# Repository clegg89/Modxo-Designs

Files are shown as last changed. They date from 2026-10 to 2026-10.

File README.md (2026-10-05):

# Modxo Designs
A set of custom [Modxo](https://github.com/Team-Resurgent/modxo) boards.

All boards have 128Mb (16MB) of flash and use a custom board variant.

## Comparison

| Feature | Micro | Mini | Mega |
| --- | ----- | ---- | ---- |
| 128Mb (16MB) of flash | ✅ | ✅ | ✅ |
| On-board RGB LED | ✅ | ✅ | ✅ |
| USB port for DFU Update | ✅ | ✅ | ✅ |
| D0 Port/Solder Pad | ✅ | ✅ | ✅ |
| Xbox I2C Port | ❌ | ✅ | ✅ |
| LCD Support | ❌ | ✅ | ✅ |
| RGB Output Port | ❌ | ✅ | ✅ |
| Expansion I2C Port | ❌ | ✅ | ✅ |
| RP2350 MCU | ❌ | ❌ | ✅ |
| UART Port | ❌ | ❌ | ✅ |
| Micro SD Card Slot | ❌ | ❌ | ✅ |
| Debug Support | ❌ | ❌ | ✅ |
| R3MUX (X3) Support | ❌ | ❌ | ✅ |

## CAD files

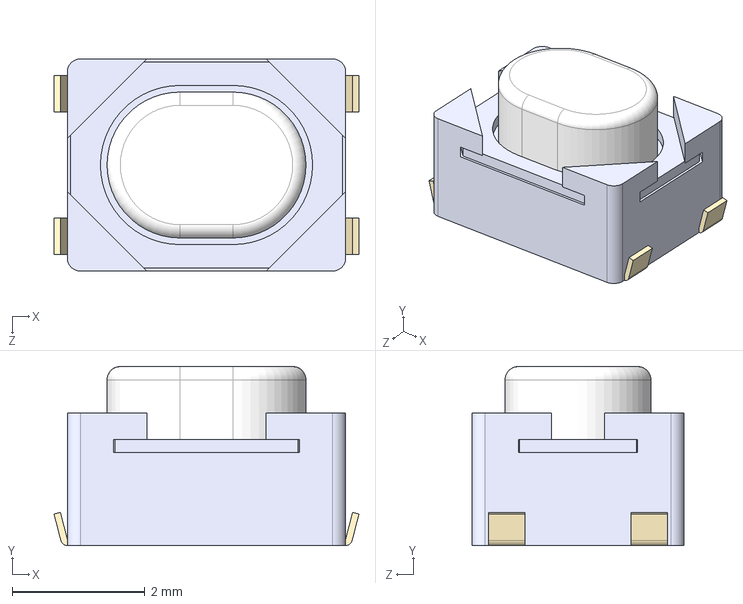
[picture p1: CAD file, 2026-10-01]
Models/PTS810SJK250SMTR LFS.STEP
4.60 x 2.70 x 3.20 mm

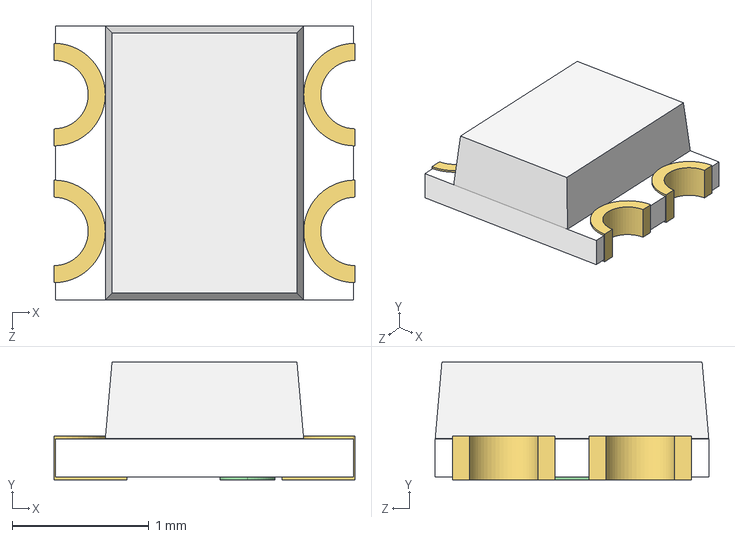
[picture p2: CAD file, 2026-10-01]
Models/WS2812-2020.STEP
2.20 x 0.86 x 2.00 mm

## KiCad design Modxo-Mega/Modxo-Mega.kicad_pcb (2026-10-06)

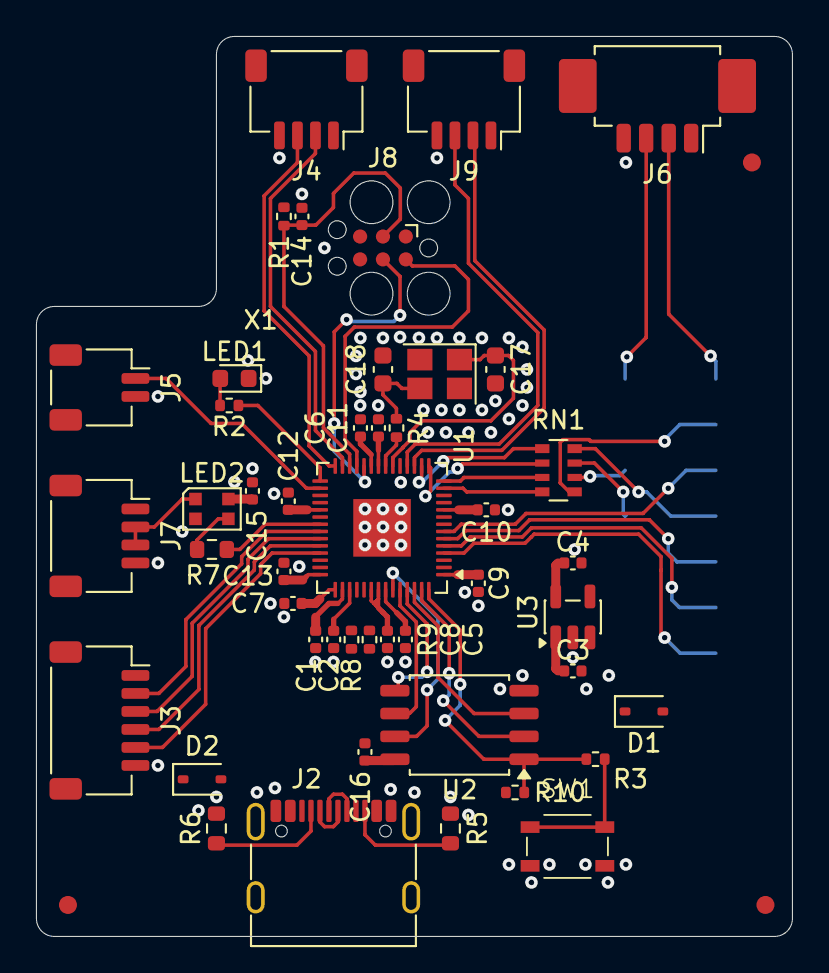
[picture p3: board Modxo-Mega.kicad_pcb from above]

Board: 2 copper layers, 42.0 x 50.0 mm, 50 parts (1 on the bottom side), 53 nets.

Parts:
C1, C2, C3, C4: 1u; C_0402_1005Metric
C5, C6, C7, C8, C9, C10, C11, C12, C13, C14, C15, C16: 100n; C_0402_1005Metric
C17, C18: 15p; C_0603_1608Metric
D1, D2: 1N5819WS; D_SOD-323
FID1, FID2, FID3: Fiducial; Fiducial_1mm_Mask2mm
J1: LPC; PinSocket_2x08_P2.54mm_Vertical_SMD
J2: USB-C; USB_C_Receptacle_G-Switch_GT-USB-7010ASV
J3: LCD; JST_SH_SM06B-SRSS-TB_1x06-1MP_P1.00mm_Horizontal
J4: UART; JST_SH_SM04B-SRSS-TB_1x04-1MP_P1.00mm_Horizontal
J5: D0; JST_SH_SM02B-SRSS-TB_1x02-1MP_P1.00mm_Horizontal
J6: OXHD; Molex_PicoBlade_53261-0471_1x04-1MP_P1.25mm_Horizontal
J7: RGB; JST_SH_SM04B-SRSS-TB_1x04-1MP_P1.00mm_Horizontal
J8: DBG; Tag-Connect_TC2030-IDC-FP_2x03_P1.27mm_Vertical
J9: EXP I2C; JST_SH_SM04B-SRSS-TB_1x04-1MP_P1.00mm_Horizontal
LED1: LED; LED_0603_1608Metric
LED2: WS2812B-2020; LED_WS2812B-2020_PLCC4_2.0x2.0mm
R1, R2, R3, R4: 1k; R_0402_1005Metric
R5, R6: 5k1; R_0603_1608Metric
R7: 470; R_0603_1608Metric
R8, R9: 27; R_0402_1005Metric
R10: DNP; R_0402_1005Metric
RN1: 100; R_Array_Convex_4x0603
SW1: Boot; SW_SPST_TS34425BA
U1: RP2040; QFN-56-1EP_7x7mm_P0.4mm_EP3.2x3.2mm
U2: W25Q128JVS; SOIC-8_5.3x5.3mm_P1.27mm
U3: AP2112K-3.3; SOT-23-5
X1: 12MHz; Crystal_SMD_Abracon_ABM8AIG-4Pin_3.2x2.5mm

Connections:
+1V1: C2.1, C5.1, C6.1, U1.23 (DVDD), U1.45 (VREG_VOUT), U1.50 (DVDD)
+3V3: C1.1, C4.1, C7.1, C8.1, C9.1, C10.1, C11.1, C12.1, C13.1, C16.1, J8.1 (VCC), R1.1, R10.1, U1.1 (IOVDD), U1.10 (IOVDD), U1.22 (IOVDD), U1.33 (IOVDD), U1.42 (IOVDD), U1.43 (ADC_AVDD), U1.44 (VREG_VIN), U1.48 (USB_VDD), U1.49 (IOVDD), U2.8 (VCC), U3.5 (VOUT)
+VBUS: D2.2 (A), J2.A4 (VBUS), J2.A9 (VBUS), J2.B4 (VBUS), J2.B9 (VBUS)
+VSYS: C3.1, C15.1, D1.1 (K), D2.1 (K), J3.1, J4.1, J6.1, J7.1, J9.1, LED2.4 (VDD), U3.1 (VIN), U3.3 (EN)
/+LPC_5V: D1.2 (A), J1.6
/D0: J5.1, U1.30 (GPIO19)
/DBG_NRST: C14.1, J8.3 (~RESET), R1.2, U1.26 (RUN)
/DBG_SWCLK: J8.4 (SWCLK), U1.24 (SWCLK)
/DBG_SWDIO: J8.2 (SWDIO), U1.25 (SWDIO)
/EXP_SCL: J9.3, U1.18 (GPIO15)
/EXP_SDA: J9.2, U1.17 (GPIO14)
/LAD0: J1.11, RN1.5 (R4.2)
/LAD0R: RN1.4 (R4.1), U1.13 (GPIO10)
/LAD1: J1.10, RN1.6 (R3.2)
/LAD1R: RN1.3 (R3.1), U1.14 (GPIO11)
/LAD2: J1.8, RN1.7 (R2.2)
/LAD2R: RN1.2 (R2.1), U1.15 (GPIO12)
/LAD3: J1.7, RN1.8 (R1.2)
/LAD3R: RN1.1 (R1.1), U1.16 (GPIO13)
/LCD_CSN1: J3.2, U1.36 (GPIO24)
/LCD_CSN2: J3.3, U1.37 (GPIO25)
/LCD_SPI_SCK: J3.4, U1.38 (GPIO26/ADC0)
/LCD_SPI_TX: J3.5, U1.39 (GPIO27/ADC1)
/LED: LED1.2 (A), R2.2
/LEDR: R2.1, U1.29 (GPIO18)
/LPC_3V3: J1.9, U1.7 (GPIO5)
/LPC_LCLK: J1.1, U1.4 (GPIO2)
/LPC_LFRAME: J1.3, U1.5 (GPIO3)
/LPC_RST: J1.5, U1.6 (GPIO4)
/QSPI_SCLK: U1.52 (QSPI_SCLK), U2.6 (CLK)
/QSPI_SD0: U1.53 (QSPI_SD0), U2.5 (DI/IO_{0})
/QSPI_SD1: U1.55 (QSPI_SD1), U2.2 (DO/IO_{1})
/QSPI_SD2: U1.54 (QSPI_SD2), U2.3 (~WP/IO_{2})
/QSPI_SD3: U1.51 (QSPI_SD3), U2.7 (~HOLD/~RESET/IO_{3})
/QSPI_SS: R3.2, R10.2, U1.56 (~QSPI_SS), U2.1 (~CS)
/RGB_DIN: LED2.3 (DIN), R7.2
/RGB_DINR: R7.1, U1.35 (GPIO23)
/RGB_DOUT: J7.2, J7.3, LED2.1 (DOUT)
/UART_RX: J4.3, U1.28 (GPIO17)
/UART_TX: J4.2, U1.27 (GPIO16)
/USBCC1: J2.A5 (CC1), R6.1
/USBCC2: J2.B5 (CC2), R5.1
/USBD+: J2.A6 (D+), J2.B6 (D+), R9.2
/USBD-: J2.A7 (D-), J2.B7 (D-), R8.2
/USB_BOOT: R3.1, SW1.1
/USB_DM-: R8.1, U1.46 (USB_DM)
/USB_DP+: R9.1, U1.47 (USB_DP)
/XIN: C17.1, U1.20 (XIN), X1.1
/XOUT: R4.1, U1.21 (XOUT)
/XOUTC: C18.2, R4.2, X1.3
/XSMBUS_SCL: J1.13, J6.2
/XSMBUS_SDA: J1.14, J6.3
GND: C1.2, C2.2, C3.2, C4.2, C5.2, C6.2, C7.2, C8.2, C9.2, C10.2, C11.2, C12.2, C13.2, C14.2, C15.2, C16.2, C17.2, C18.1, J1.2, J1.12, J2.A1 (GND), J2.A12 (GND), J2.B1 (GND), J2.B12 (GND), J2.SH (SHIELD), J3.6, J3.MP (MountPin), J4.4, J4.MP (MountPin), J5.2, J5.MP (MountPin), J6.4, J6.MP (MountPin), J7.4, J7.MP (MountPin), J8.5 (GND), J9.4, J9.MP (MountPin), LED1.1 (K), LED2.2 (VSS), R5.2, R6.2, SW1.2, U1.19 (TESTEN), U1.57 (GND), U2.4 (GND), U3.2 (GND), X1.2 (G), X1.4 (G)

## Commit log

2026-10-01 Port previous design for mega
    [Modxo-Mega.kicad_pcb, Modxo-Mega.kicad_sch, PTS810SJK250SMTR LFS.STEP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]
2026-10-02 Cleanup schematic
    [Modxo-Mega.kicad_sch, connectors.kicad_sch, mcu.kicad_sch]
2026-10-05 Add SD Card, other minor changes
    [Modxo-Mega.kicad_sch, connectors.kicad_sch, mcu.kicad_sch]
2026-10-05 Begin saving symbols to library
    [connectors.kicad_sch, mcu.kicad_sch]
2026-10-05 Continue work
    [mcu.kicad_sch]
2026-10-06 Move most symbols to library
    [Modxo-Mega.kicad_pcb, connectors.kicad_sch, mcu.kicad_sch]
